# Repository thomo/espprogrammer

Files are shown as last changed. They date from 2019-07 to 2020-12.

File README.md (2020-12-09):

# ESP Programmer

It is a small board which add just some logic to provide ESP-12 auto programming using a CP2104 board. Just connect the board to your ESP-12 board and you can upload your code like when using a Nodemcu board.

Design is based on information from

- <https://tttapa.github.io/ESP8266/Chap06%20-%20Uploading.html>
- <https://github.com/nodemcu/nodemcu-devkit-v1.0/blob/master/NODEMCU_DEVKIT_V1.0.PDF>

## Prototype

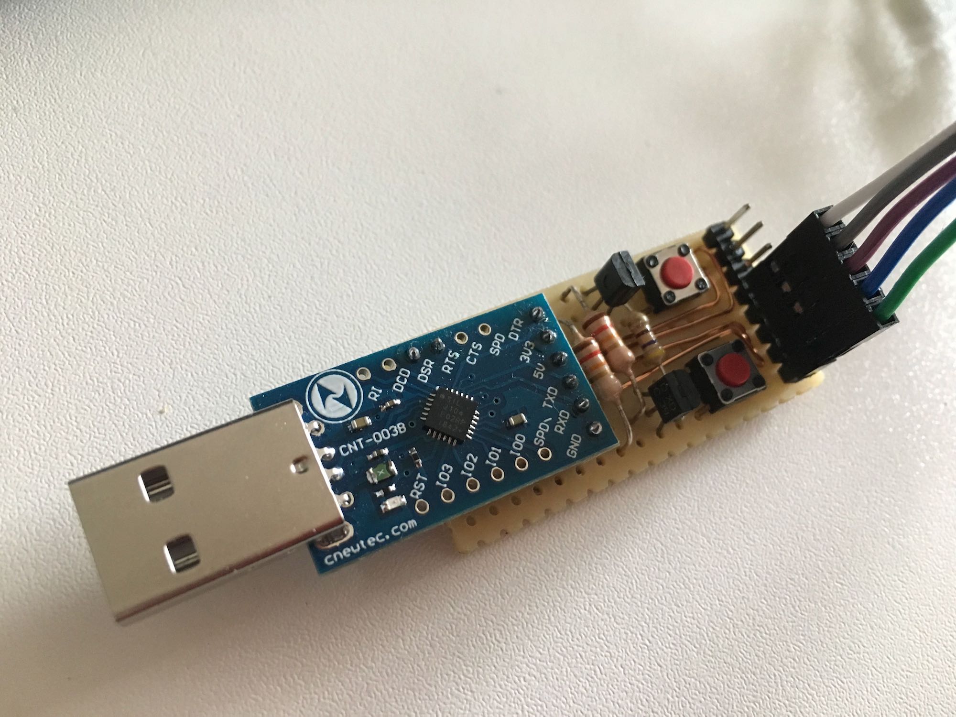
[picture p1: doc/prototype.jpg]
Prototype


## Circuit

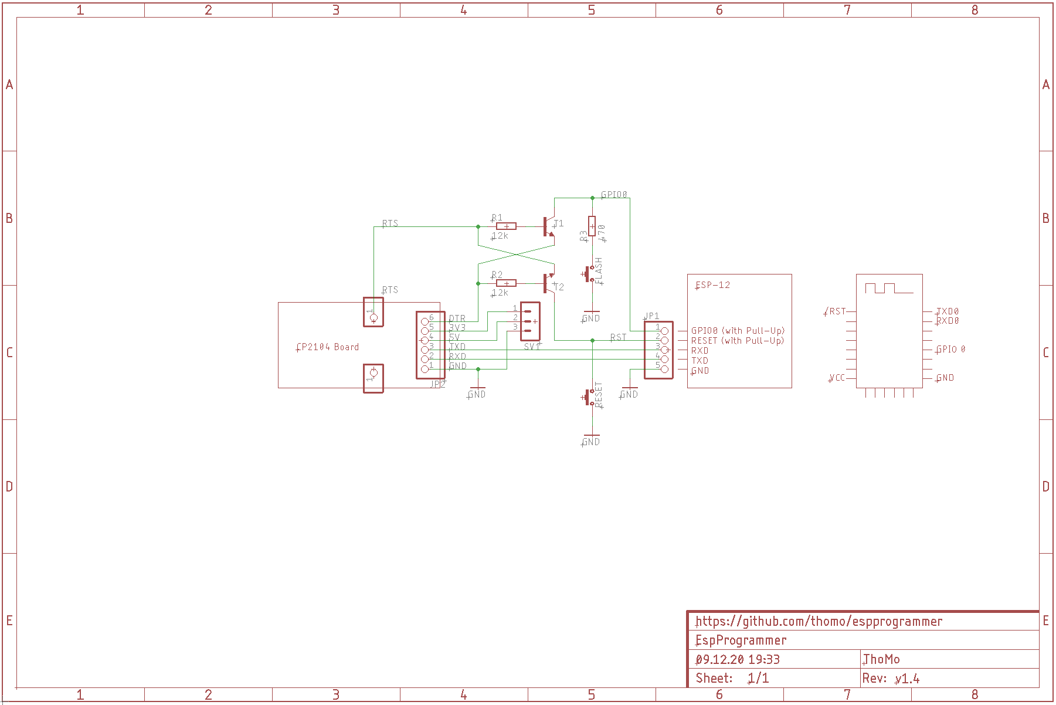
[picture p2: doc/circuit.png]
Circuit


## PCB

The board can be ordered from OSH Park: 

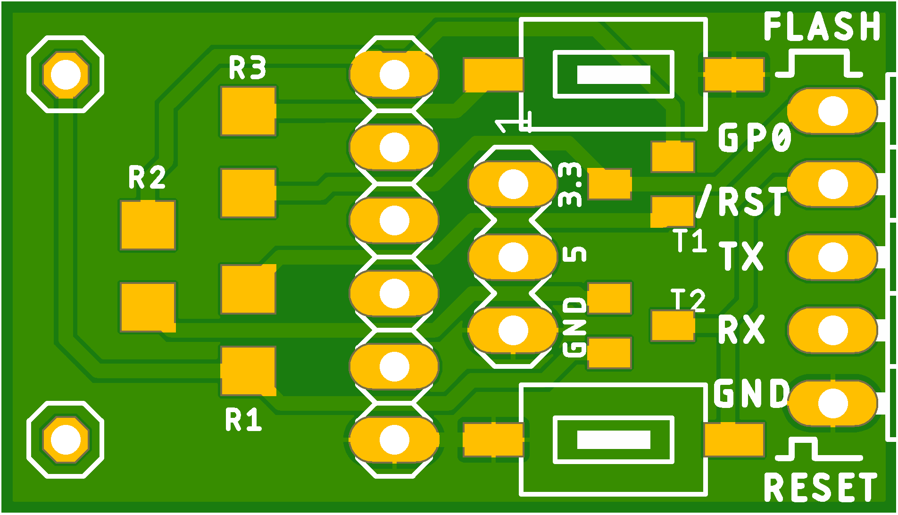
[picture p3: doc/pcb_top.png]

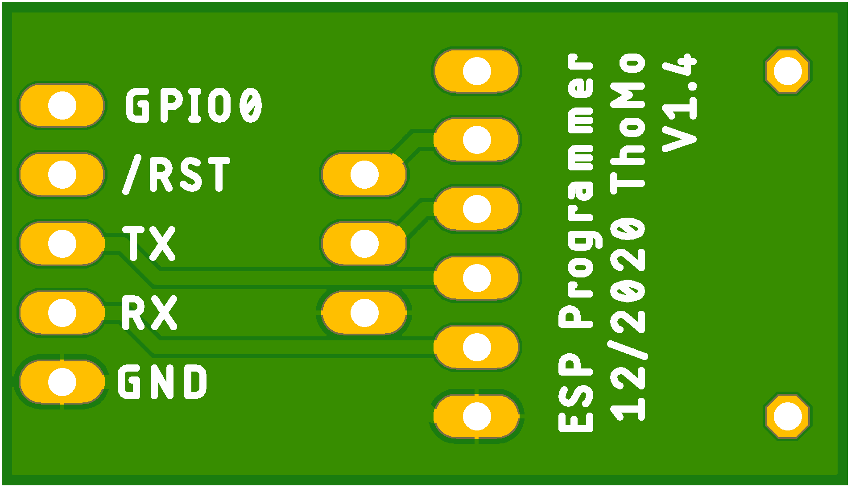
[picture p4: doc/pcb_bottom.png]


## License

[MIT License](LICENSE)

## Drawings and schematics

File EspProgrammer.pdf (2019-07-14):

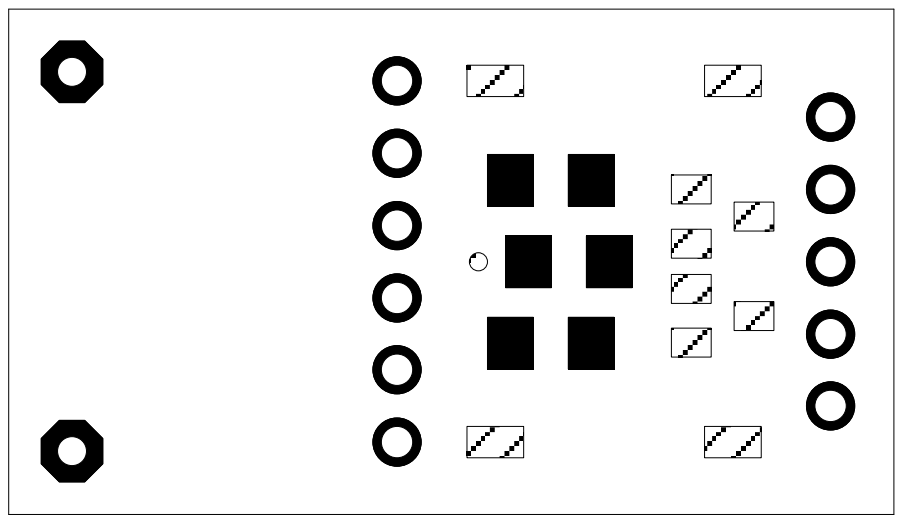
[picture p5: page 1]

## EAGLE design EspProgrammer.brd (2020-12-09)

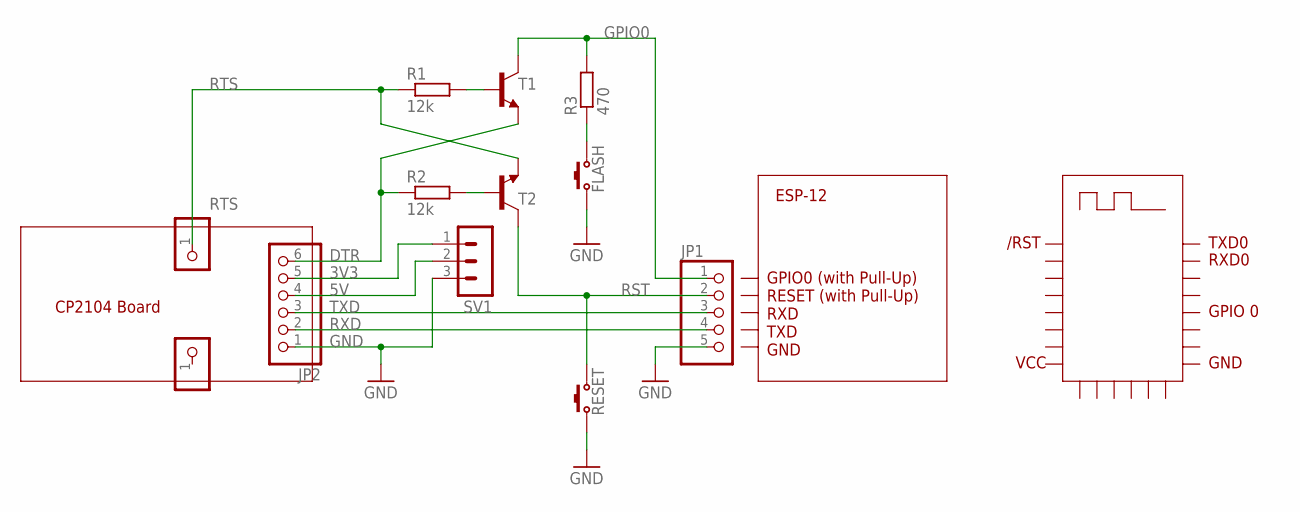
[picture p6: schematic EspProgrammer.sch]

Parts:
FLASH: KEY; SMD-BUTTON
JP1: PINHD-1X5/90; 1X05/90
JP2: PINHD-1X6; 1X06
LSP2, LSP3: PINHD-1X1; 1X01
R1, R2: 12k; R1206
R3: 470; R1206
RESET: KEY; SMD-BUTTON
SV1: MA03-1
T1, T2: BC817-40LT1SMD; SOT23-BEC

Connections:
3V3: JP2.5, SV1.1
5V: JP2.4, SV1.2
DTR: JP2.6, R2.1, T1.E
GND: FLASH.2, JP1.5, JP2.1, RESET.2, SV1.3
GPIO0: JP1.1, R3.2, T1.C
unnamed: R1.2, T1.B
unnamed: R2.2, T2.B
unnamed: FLASH.1, R3.1
RST: JP1.2, RESET.1, T2.C
RTS: LSP3.1, R1.1, T2.E
RXD: JP1.4, JP2.2
TXD: JP1.3, JP2.3

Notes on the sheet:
CP2104 Board
ESP-12
GPIO0 (with Pull-Up) RESET (with Pull-Up) RXD TXD GND
GPIO 0
/RST
VCC
GND
TXD0
RXD0

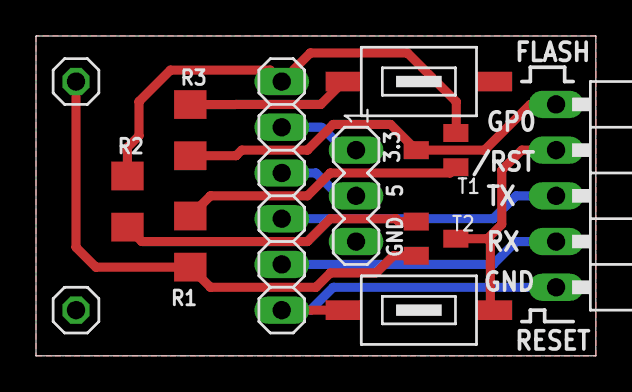
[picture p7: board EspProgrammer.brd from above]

Board: 2 copper layers, 31.1 x 17.8 mm, 12 parts (0 on the bottom side), 12 nets.

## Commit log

2019-07-14 version 1.0
    [EspProgrammer.brd, EspProgrammer.sch]
2019-07-14 add documentation
    [EspProgrammer.sch]
2020-12-09 change transistor package
    [EspProgrammer.brd, EspProgrammer.sch]

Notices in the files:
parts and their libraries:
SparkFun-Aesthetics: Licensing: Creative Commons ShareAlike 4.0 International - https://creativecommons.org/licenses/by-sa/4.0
